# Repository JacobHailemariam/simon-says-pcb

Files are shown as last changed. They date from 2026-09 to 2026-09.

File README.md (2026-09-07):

# Simon Says — Custom PCB and Embedded Firmware

A Simon Says memory game built end-to-end: schematic capture, custom PCB
layout, fabrication release, firmware, and hardware bring-up.

The player watches a sequence of LED flashes and repeats it on four buttons.
Each round adds one step to the sequence.

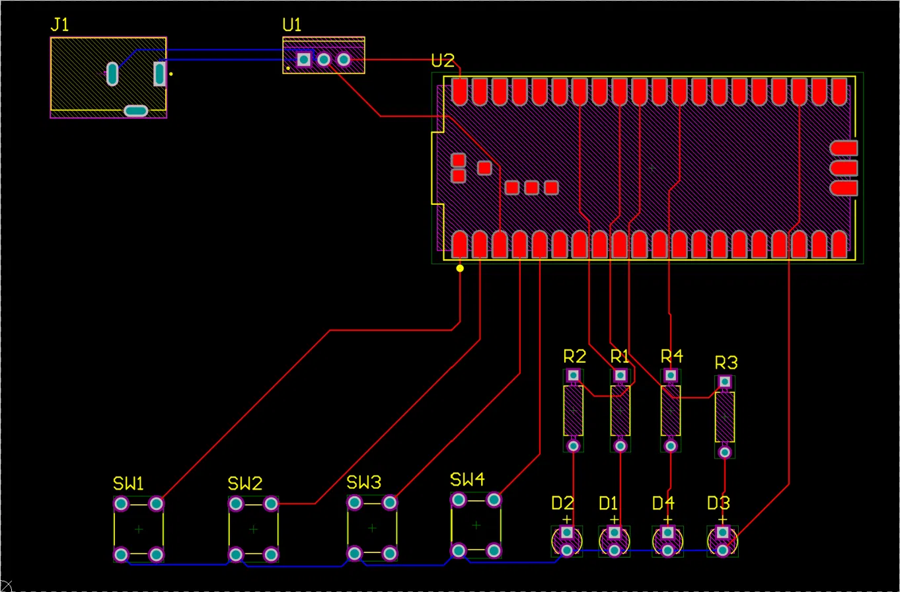
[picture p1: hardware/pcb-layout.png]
PCB layout


## Hardware

A 2-layer FR-4 board designed in Altium Designer, roughly 115 x 75 mm, built
entirely from through-hole parts. Signals route on the top layer with ground
returned on the bottom. Power comes from a barrel jack through a linear
regulator rather than USB, so the board runs standalone.

| Ref | Part | Notes |
| --- | --- | --- |
| U2 | Raspberry Pi Pico (SC0915) | RP2040, 49-pin module |
| U1 | L7805CV | 5 V linear regulator, TO-220 |
| J1 | PJ-102A | 2.0 x 6.5 mm DC barrel jack |
| SW1-SW4 | TS-1109 | Tactile SPST, 4-pin through-hole |
| 4x LED | 304090040 | Green, 20 mA, 2-pin through-hole |
| 4x R | MFR-25FBF52-100R | 100 ohm, 1%, 0.25 W, axial |

**Stackup:** Top copper / FR-4 core 59 mil (Dk 4.3) / bottom copper,
0.7 mil copper per layer, solder resist both sides.

### Pin mapping

| Function | GPIO |
| --- | --- |
| SW1-SW4 | GP0, GP1, GP2, GP3 |
| LEDs | GP28, GP27, GP26, GP22 |

Buttons pull to ground with no external pull-up resistors on the board, so
the RP2040's internal pull-ups are enabled in firmware and a pressed button
reads logic 0.

## Firmware

MicroPython, in `firmware/main.py`.

Each round appends one random step to the sequence and plays the whole thing
back, then reads the player's entries one at a time and compares against the
target. A wrong entry runs a failure animation and clears the sequence.

Two details worth calling out:

**Release-edge detection.** Reading the button level in a loop counts one
press per iteration for as long as the button is held, so a single long press
registers as several entries. `wait_for_release()` blocks until the contact
opens again before the press is accepted.

**Hardware-seeded PRNG.** Without an explicit seed, the game can deal an
identical sequence on every power cycle. `os.urandom()` on the RP2040 draws
from the ring oscillator, so each boot starts from a different state.

## Flashing

1. Install MicroPython on the Pico (hold BOOTSEL while plugging in via USB,
   then drag the UF2 onto the drive that appears).
2. Copy `firmware/main.py` to the board:

```
pip install mpremote
mpremote connect list
mpremote fs cp firmware/main.py :main.py
```

The game starts automatically on power-up once `main.py` is on the board.

## Known issues

- **No decoupling capacitors on the regulator.** The L7805 datasheet calls
  for roughly 0.33 uF on the input and 0.1 uF on the output. Neither is on
  the current board.
- **Regulator library mismatch.** The placed schematic symbol comes from an
  L4940 library part while the comment field reads L7805CV. The two are
  pin-compatible in TO-220 so the board works, but a generated BOM would
  order the wrong regulator.
- **No audio.** The board has no buzzer or driver circuitry, so gameplay is
  visual only.

## Repository layout

```
simon-says-pcb/
├── README.md
├── firmware/
│   └── main.py
└── hardware/
    ├── JacobSimonSays.SchDoc
    ├── PCB1.PcbDoc
    ├── schematic.png
    └── pcb-layout.png
```

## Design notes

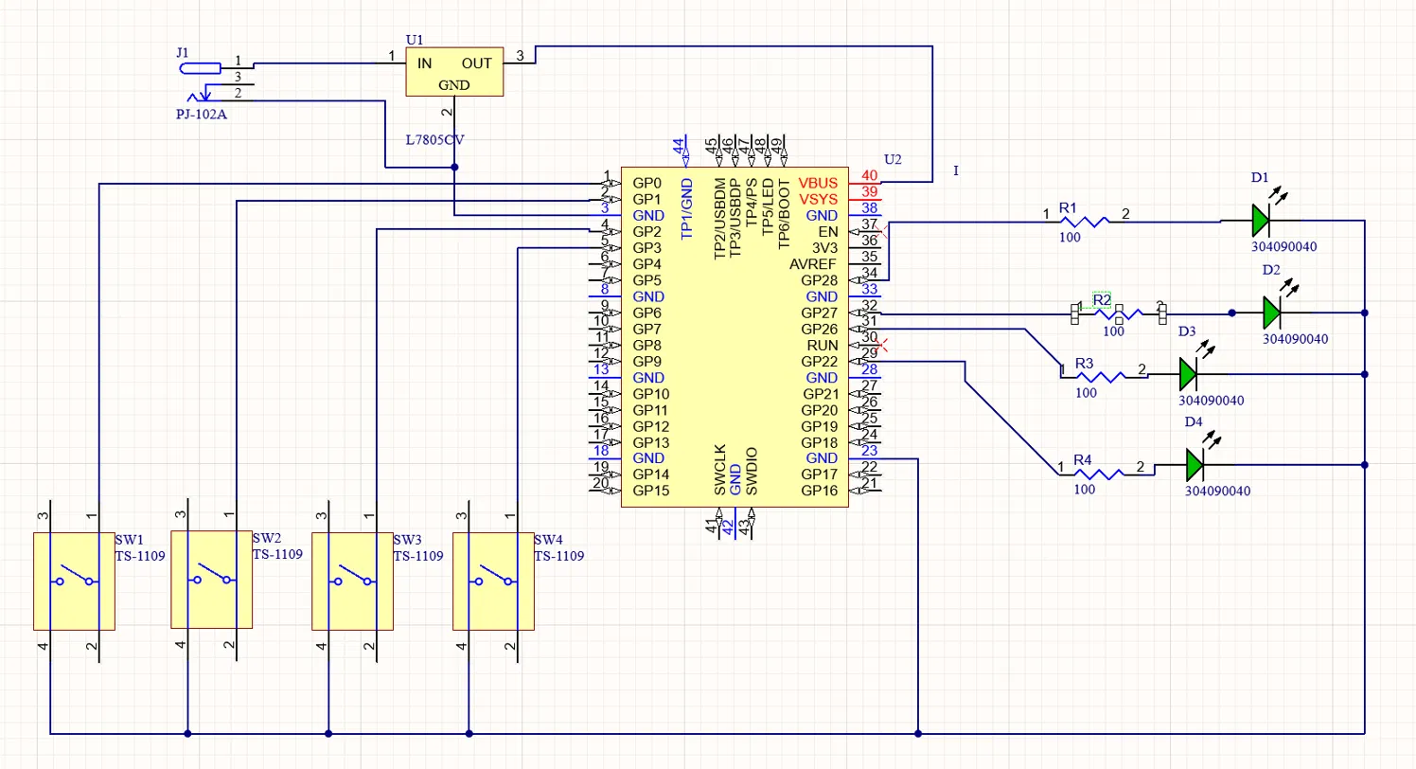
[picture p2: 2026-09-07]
hardware/schematic.png

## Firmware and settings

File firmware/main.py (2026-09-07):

"""
Simon Says memory game
Raspberry Pi Pico (RP2040) on a custom 2-layer PCB

Hardware mapping (matches JacobSimonSays.SchDoc):
    GP0, GP1, GP2, GP3      -> SW1-SW4, TS-1109 tactile switches to GND
                               Internal pull-ups are enabled, so a pressed
                               button reads 0. There are no external pull-up
                               resistors on the board.
    GP28, GP27, GP26, GP22  -> LEDs through 100 ohm series resistors

Gameplay:
    Each round appends one new random step to the sequence, plays the whole
    sequence back, then waits for the player to repeat it. A wrong entry
    triggers a failure animation and resets the sequence.
"""

from machine import Pin
import os
import random
import time

BUTTON_PINS = (0, 1, 2, 3)
LED_PINS = (28, 27, 26, 22)

FLASH_MS = 300          # how long each LED stays lit during playback
GAP_MS = 200            # dark time between playback steps
PRESS_FEEDBACK_MS = 150 # how long the LED lights when the player presses
DEBOUNCE_MS = 20        # settling time after a contact change
START_DELAY_MS = 700    # pause before a sequence is played back


def seed_random():
    """
    Seed the PRNG from hardware entropy.

    Without this, MicroPython may start from the same internal state on every
    power cycle, which makes the game deal an identical sequence every time
    the board is plugged in. os.urandom() on the RP2040 draws from the ring
    oscillator, so each boot starts somewhere different.
    """
    seed_bytes = os.urandom(4)
    random.seed(int.from_bytes(seed_bytes, "big"))


def wait_for_release(button):
    """
    Block until the button is let go, then let the contact settle.

    This is what stops a single held press from registering as several
    entries. Polling the button level alone counts one press per loop
    iteration for as long as it is held down.
    """
    while button.value() == 0:
        time.sleep_ms(DEBOUNCE_MS)
    time.sleep_ms(DEBOUNCE_MS)


def flash(led, on_ms=FLASH_MS, off_ms=GAP_MS):
    led.on()
    time.sleep_ms(on_ms)
    led.off()
    time.sleep_ms(off_ms)


def play_sequence(sequence, leds):
    time.sleep_ms(START_DELAY_MS)
    for index in sequence:
        flash(leds[index])


def read_player_press(buttons, leds):
    """
    Wait for one button press and return its index.

    The LED for the pressed button is lit briefly so the player gets
    confirmation on every entry rather than only at the end of the round.
    """
    while True:
        for index, button in enumerate(buttons):
            if button.value() == 0:
                wait_for_release(button)
                flash(leds[index], PRESS_FEEDBACK_MS, 0)
                return index
        time.sleep_ms(5)


def play_failure_animation(leds):
    for led in leds:
        flash(led, 150, 0)
    for led in reversed(leds):
        flash(led, 150, 0)
    time.sleep_ms(1000)


def main():
    buttons = [Pin(pin, Pin.IN, Pin.PULL_UP) for pin in BUTTON_PINS]
    leds = [Pin(pin, Pin.OUT) for pin in LED_PINS]

    seed_random()
    sequence = []

    while True:
        sequence.append(random.randrange(len(leds)))
        play_sequence(sequence, leds)

        for expected in sequence:
            if read_player_press(buttons, leds) != expected:
                print("Wrong. Sequence length reached:", len(sequence) - 1)
                play_failure_animation(leds)
                sequence = []
                break
        else:
            print("Correct. Sequence length:", len(sequence))


main()

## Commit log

2026-09-07 Initial commit: Simon Says PCB and firmware
    [JacobSimonSays.SchDoc, PCB1.PcbDoc]
2026-09-07 Add files via upload
    new 2nd photos for schematic and pcb layout
